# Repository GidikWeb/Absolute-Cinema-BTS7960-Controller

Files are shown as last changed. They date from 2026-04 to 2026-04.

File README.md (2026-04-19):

# D-LEEK Massage Controller / BTS7960 Professional Driver



[]()



**Профессиональный контроллер для массажного аппарата D-LEEK**  
*Победитель регионального этапа Всероссийского конкурса "Юные техники и инновационные лидеры" (2025)*

---

## 📌 О проекте

**D-LEEK** — это открытая, недорогая и функциональная альтернатива дорогостоящим реабилитационным аппаратам (таким как R-Sleek или LPG). Устройство предназначено для медицинской реабилитации после травм, неврологических заболеваний, переломов, а также для восстановительной терапии в домашних условиях.

### 🎯 Ключевые особенности

- **Низкая стоимость** — менее 15 000 рублей (в 100+ раз дешевле аналогов)
- **Профессиональный функционал**:
  - Плавный разгон и торможение (Ramping)
  - Защита по току (Overcurrent protection)
  - Таймер безопасности непрерывной работы
  - 9 предустановленных программ массажа
  - Редактор пользовательских программ (до 5 программ, 10 шагов каждая)
- **Интуитивный интерфейс** — LCD 16×2 с кастомными иконками
- **Управление** — 3 кнопки (Up/OK/Down) + Serial команды
- **Автономность** — все настройки сохраняются в EEPROM

---

## 🧠 Для кого этот проект

- **Пациентам** для самостоятельной реабилитации (под контролем врача)
- **Начинающим реабилитологам и массажистам** для выездной работы
- **Малым медицинским центрам и ФАПам** с ограниченным бюджетом
- **Makers и инженерам**, желающим собрать профессиональный массажёр своими руками

---

## ⚙️ Аппаратная платформа

| Компонент | Модель / Спецификация |
|---|---|
| Микроконтроллер | Arduino Uno (или совместимый) |
| Драйвер двигателя | BTS7960 (43A пик, 27V max) |
| Двигатель | Коллекторный 12V (3-5A рабочий ток) |
| Дисплей | LCD 16×2 с I²C (адрес 0x27) |
| Кнопки | 3 тактовых (BTN_UP, BTN_OK, BTN_DOWN) |
| Питание | Блок питания 12В 5А |
| Корпус и ручка | 3D-печать (PLA) / распределительная коробка |

### Схема подключения (пины Arduino)

| Пин | Назначение |
|-----|---|
| A0  | R_IS (ток) |
| A1  | L_IS (ток) |
| 2 | R_EN |
| 3 | R_PWM |
| 4 | L_EN |
| 5 | L_PWM |
| 8 | BTN_UP |
| 9 | BTN_OK |
| 10  | BTN_DOWN |
| A4  | SDA (I²C дисплей) |
| A5  | SCL (I²C дисплей) |

> Полная схема доступна в [схема/](schematic/)

---

## 🖥️ Программное обеспечение

- **Среда разработки**: VS Code + PlatformIO (или Arduino IDE)
- **Язык**: C++ (Arduino framework)
- **Библиотеки**:
  - `LiquidCrystal_I2C` — управление дисплеем
  - `EEPROM` — хранение настроек
  - `avr/pgmspace.h` — хранение констант в PROGMEM

### 🔁 Конечный автомат состояний

Поддерживаются следующие режимы:
- MAIN_MENU
- SPEED_SETTING
- DIRECTION_SETTING
- TIMER_SETTING
- SAFETY_SETTING
- TIMER_RUNNING
- PROGRAM_MENU / PROGRAM_RUNNING
- AUTO_TEST
- EDITOR_INPUT / EDITOR_NAME / EDITOR_SELECT / EDITOR_EDIT_STEPS

---

## 🎮 Управление

### Через кнопки
- **UP** — увеличение значения / навигация вверх
- **DOWN** — уменьшение значения / навигация вниз / остановка
- **OK** — подтверждение / вход в меню / пауза/возобновление

### Через Serial (115200 бод)

| Команда | Описание |
|---|---|
| `ON` / `OFF` | Включить / выключить мотор |
| `SPEED 150` | Установить скорость (0-255) |
| `DIR F` / `DIR R` | Направление: Forward / Reverse |
| `TIMER 10` | Установить таймер (минут) |
| `START_TIMER` / `STOP_TIMER` | Запуск / остановка таймера |
| `SAFETY 30` | Тайм-аут безопасности (мин) |
| `LIST` | Список всех программ |
| `RUN 2` | Запустить программу по индексу |
| `STOP` / `PAUSE` / `RESUME` | Управление программой |
| `PROG_INFO 0` | Показать шаги программы |
| `EDITOR_NEW` | Создать новую программу |
| `EDITOR_ADD_STEP 150 1 30` | Добавить шаг (скорость, направление, секунды) |
| `EDITOR_SET_NAME MyProg` | Задать имя программы |
| `EDITOR_SAVE` | Сохранить программу в EEPROM |
| `AUTO_TEST` | Запустить автоматическое тестирование |
| `HELP` | Показать все команды |

---

## 📦 Предустановленные программы массажа

| №  | Название | Особенность |
|----|---|---|
| 0  | Hard | Интенсивный, длительные шаги |
| 1  | Relax | Мягкий, расслабляющий |
| 2  | Body | Общеукрепляющий |
| 3  | Arms | Для рук и плечевого пояса |
| 4  | Legs | Для ног |
| 5  | Kneading | Разминание с переменной скоростью |
| 6  | Vibration | Быстрое чередование направлений |
| 7  | Tapping | Имитация постукивания (вкл/выкл) |
| 8  | Lymphatic | Длительный лимфодренаж (60 мин) |

> Пользовательские программы сохраняются в EEPROM (до 5 штук, до 10 шагов).

---

## 🔧 Сборка и настройка

### 1. Установка зависимостей

**Arduino IDE**:
- Установите библиотеку `LiquidCrystal_I2C` через менеджер библиотек

**PlatformIO**:
```ini
[env:uno]
platform = atmelavr
board = uno
framework = arduino
lib_deps = 
    liquidcrystal-i2c

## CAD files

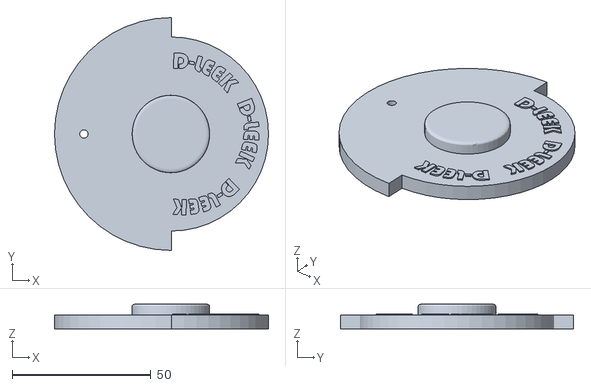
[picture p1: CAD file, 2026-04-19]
3d_models/Upper.stl
77.2 x 84.0 x 9.00

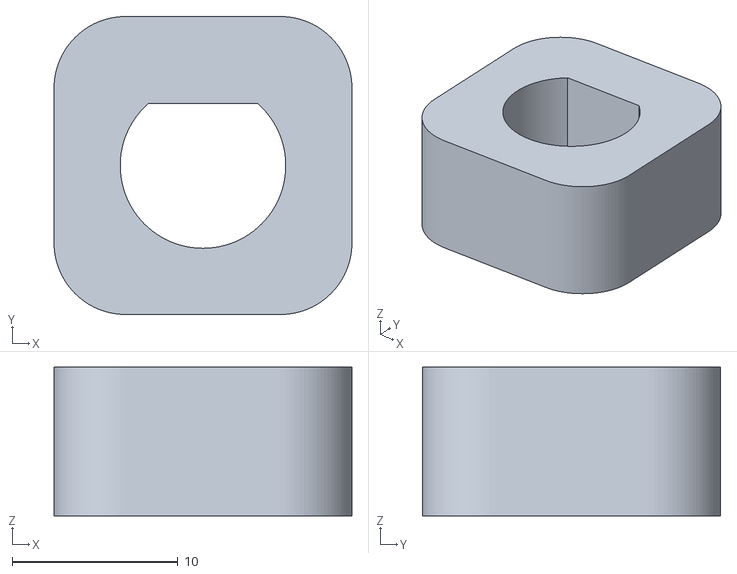
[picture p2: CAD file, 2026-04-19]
3d_models/Locker.stl
18.0 x 18.0 x 9.00

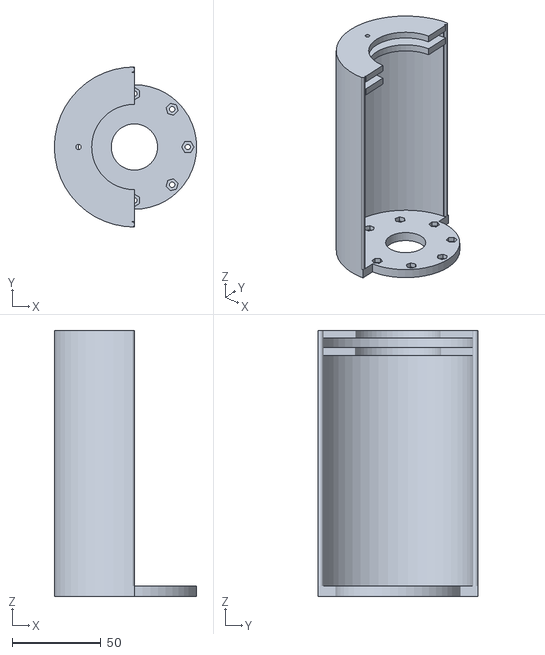
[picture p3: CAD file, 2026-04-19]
3d_models/Handle.stl
80.0 x 90.0 x 149.5

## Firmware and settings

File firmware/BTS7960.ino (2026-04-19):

#include <Wire.h>
#include <LiquidCrystal_I2C.h>
#include <EEPROM.h>
#include <avr/pgmspace.h>

// ========== BTS7960 PINS ==========
int R_IS = A0;
int L_IS = A1;
int R_EN = 2;
int R_PWM = 3;
int L_EN = 4;
int L_PWM = 5;

// ========== BUTTON PINS ==========
#define BTN_UP    8
#define BTN_OK    9
#define BTN_DOWN  10

// ========== LCD I2C ==========
LiquidCrystal_I2C lcd(0x27, 16, 2);

// ========== CUSTOM CHARACTERS (PROGMEM) ==========
const byte char_arrowLeft[8] PROGMEM      = {0b00000,0b00100,0b01000,0b11111,0b01000,0b00100,0b00000,0b00000};
const byte char_timerIcon[8] PROGMEM      = {0b00000,0b01110,0b10101,0b10111,0b10001,0b01110,0b00000,0b00000};
const byte char_pauseIcon[8] PROGMEM      = {0b00000,0b11011,0b11011,0b11011,0b11011,0b11011,0b11011,0b00000};
const byte char_playIcon[8] PROGMEM       = {0b00000,0b01100,0b01110,0b01111,0b01111,0b01110,0b01100,0b00000};
const byte char_speedIcon7[8] PROGMEM     = {0b00000,0b01110,0b10001,0b10101,0b10011,0b11111,0b00000,0b00000};
const byte char_powerOn[8] PROGMEM        = {0b11111,0b11111,0b11011,0b11011,0b11011,0b01110,0b10001,0b11111};
const byte char_powerOff[8] PROGMEM       = {0b00000,0b00000,0b00100,0b00100,0b10101,0b10001,0b01110,0b00000};
const byte char_menuIcon[8] PROGMEM       = {0b00000,0b00000,0b11111,0b00000,0b11111,0b00000,0b11111,0b00000};
const byte char_arrowRight[8] PROGMEM     = {0b00000,0b00100,0b00010,0b11111,0b00010,0b00100,0b00000,0b00000};
const byte char_speedIcon6[8] PROGMEM     = {0b00000,0b01110,0b10001,0b10111,0b10001,0b11111,0b00000,0b00000};
const byte char_speedIcon5[8] PROGMEM     = {0b00000,0b01110,0b10011,0b10101,0b10001,0b11111,0b00000,0b00000};
const byte char_speedIcon4[8] PROGMEM     = {0b00000,0b01110,0b10101,0b10101,0b10001,0b11111,0b00000,0b00000};
const byte char_speedIcon3[8] PROGMEM     = {0b00000,0b01110,0b11001,0b10101,0b10001,0b11111,0b00000,0b00000};
const byte char_speedIcon2[8] PROGMEM     = {0b00000,0b01110,0b10001,0b11101,0b10001,0b11111,0b00000,0b00000};
const byte char_speedIcon1[8] PROGMEM     = {0b00000,0b01110,0b10001,0b10101,0b11001,0b11111,0b00000,0b00000};
const byte char_newIcon[8] PROGMEM        = {0b00000,0b00000,0b00100,0b00100,0b11111,0b00100,0b00100,0b00000};
const byte char_deleteIcon[8] PROGMEM     = {0b00000,0b00000,0b00000,0b00000,0b11111,0b00000,0b00000,0b00000};
const byte char_powerMenu[8] PROGMEM      = {0b00010,0b00110,0b01100,0b11111,0b00011,0b00110,0b00100,0b00000};
const byte char_directionMenu[8] PROGMEM  = {0b00100,0b01111,0b00101,0b00001,0b10001,0b10001,0b11111,0b00000};
const byte char_speedMenu[8] PROGMEM      = {0b00000,0b01110,0b10001,0b10101,0b10011,0b11111,0b00000,0b00000};
const byte char_timersMenu[8] PROGMEM     = {0b00000,0b01110,0b10101,0b10111,0b10001,0b01110,0b00000,0b00000};
const byte char_safetyMenu[8] PROGMEM     = {0b01110,0b10001,0b10001,0b11111,0b11111,0b11011,0b11111,0b00000};
const byte char_massageMenu[8] PROGMEM    = {0b00000,0b00000,0b01010,0b11011,0b00000,0b11011,0b01010,0b00000};
const byte char_editorMenu[8] PROGMEM     = {0b00001,0b00000,0b01010,0b11011,0b00000,0b11011,0b01010,0b00000};
const byte char_autotestMenu[8] PROGMEM   = {0b00000,0b00000,0b00100,0b01110,0b11011,0b01110,0b00100,0b00000};
// Песочные часы (степень заполнения)
const byte timeLeft1[8] PROGMEM           = {0b00000,0b11111,0b10001,0b01010,0b00100,0b01010,0b10001,0b11111};
const byte timeLeft2[8] PROGMEM           = {0b00000,0b11111,0b10001,0b01010,0b00100,0b01010,0b11111,0b11111};
const byte timeLeft3[8] PROGMEM           = {0b00000,0b11111,0b10001,0b01010,0b00100,0b01110,0b11111,0b11111};
const byte timeLeft4[8] PROGMEM           = {0b00000,0b11111,0b10001,0b01110,0b00100,0b01110,0b11111,0b11111};
const byte timeLeft5[8] PROGMEM           = {0b00000,0b11111,0b11111,0b01110,0b00100,0b01110,0b11111,0b11111};

void loadCharFromProgmem(uint8_t slot, const byte* data) {
  byte buffer[8];
  for (int i = 0; i < 8; i++) buffer[i] = pgm_read_byte(&data[i]);
  lcd.createChar(slot, buffer);
}

// ========== EEPROM ADDRESSES ==========
const int EEPROM_SIGNATURE = 0xAA;
const int ADDR_SIGNATURE = 0;
const int ADDR_SPEED     = 1;
const int ADDR_DIRECTION = 2;
const int ADDR_TIMER_MIN = 3;
const int ADDR_SAFETY_TIMEOUT = 4;

#define USER_PROG_START  100
#define USER_PROG_MAX    5
#define USER_PROG_STEPS_MAX 10
#define USER_NAME_LEN    12

// ========== SAFETY SETTINGS ==========
int MAX_CONTINUOUS_MINUTES = 30;
const int CURRENT_THRESHOLD = 600;
unsigned long motorStartTime = 0;
bool safetyTimerActive = false;

// ========== SMOOTH RAMPING ==========
const unsigned long RAMP_TIME_MS = 400;
int currentSpeed = 0;
int targetSpeed = 0;
bool targetEnabled = false;
unsigned long rampStartTime = 0;
bool ramping = false;

// ========== GLOBAL VARIABLES ==========
enum MenuState {
  MAIN_MENU,
  SPEED_SETTING,
  DIRECTION_SETTING,
  TIMER_SETTING,
  SAFETY_SETTING,
  TIMER_RUNNING,
  PROGRAM_MENU,
  PROGRAM_RUNNING,
  AUTO_TEST,
  EDITOR_INPUT,
  EDITOR_NAME,
  EDITOR_SELECT,
  EDITOR_EDIT_STEPS
};

MenuState currentState = MAIN_MENU;
int menuIndex = 0;
bool motorEnabled = false;
int motorSpeed = 150;
bool motorDirection = true;
int timerMinutes = 5;
int safetyMinutes = 30;

bool backgroundTimerActive = false;
unsigned long backgroundTimerEndTime = 0;
bool timerPaused = false;
unsigned long pauseAccumulated = 0;

int currentProgram = -1;
int currentStep = 0;
unsigned long stepStartTime = 0;
unsigned long stepPauseAccum = 0;
bool programPaused = false;

// ========== FACTORY PROGRAMS (PROGMEM) ==========
struct ProgramStep {
  uint8_t speed;
  bool direction;
  uint16_t durationSec;
};

#define readStepSpeed(ptr)   pgm_read_byte(&(ptr)->speed)
#define readStepDir(ptr)     pgm_read_byte(&(ptr)->direction)
#define readStepDur(ptr)     pgm_read_word(&(ptr)->durationSec)

const ProgramStep programHard[] PROGMEM = {
  {200, true, 600}, {180, false, 300}, {220, true, 450}, {150, false, 600}, {0, false, 0}
};
const ProgramStep programRelax[] PROGMEM = {
  {120, true, 600}, {100, false, 600}, {80, true, 300}, {0, false, 0}
};
const ProgramStep programBody[] PROGMEM = {
  {180, true, 600}, {200, false, 600}, {160, true, 600}, {0, false, 0}
};
const ProgramStep programArms[] PROGMEM = {
  {150, true, 300}, {130, false, 300}, {170, true, 300}, {140, false, 300}, {0, false, 0}
};
const ProgramStep programLegs[] PROGMEM = {
  {220, true, 600}, {200, false, 600}, {180, true, 300}, {0, false, 0}
};
const ProgramStep programKneading[] PROGMEM = {
  {180, true, 600}, {160, false, 600}, {200, true, 600}, {140, false, 300}, {170, true, 300}, {0, false, 0}
};
const ProgramStep programVibration[] PROGMEM = {
  {120, true, 2}, {120, false, 2}, {120, true, 2}, {120, false, 2},
  {130, true, 2}, {130, false, 2}, {130, true, 2}, {130, false, 2},
  {140, true, 2}, {140, false, 2}, {140, true, 2}, {140, false, 2},
  {150, true, 2}, {150, false, 2}, {150, true, 2}, {150, false, 2},
  {160, true, 2}, {160, false, 2}, {160, true, 2}, {160, false, 2},
  {170, true, 2}, {170, false, 2}, {170, true, 2}, {170, false, 2},
  {180, true, 2}, {180, false, 2}, {180, true, 2}, {180, false, 2},
  {0, false, 0}
};
const ProgramStep programTapping[] PROGMEM = {
  {220, true, 2}, {0, true, 1}, {220, true, 2}, {0, true, 1},
  {200, true, 2}, {0, true, 1}, {200, true, 2}, {0, true, 1},
  {180, true, 2}, {0, true, 1}, {180, true, 2}, {0, true, 1},
  {160, true, 2}, {0, true, 1}, {160, true, 2}, {0, true, 1},
  {140, true, 2}, {0, true, 1}, {140, true, 2}, {0, true, 1},
  {120, true, 2}, {0, true, 1}, {120, true, 2}, {0, true, 1},
  {0, false, 0}
};
const ProgramStep programLymphatic[] PROGMEM = {
  {100, true, 3600}, {0, false, 0}
};

PGM_P const factoryPrograms[] PROGMEM = {
  (PGM_P)programHard, (PGM_P)programRelax, (PGM_P)programBody,
  (PGM_P)programArms, (PGM_P)programLegs, (PGM_P)programKneading,
  (PGM_P)programVibration, (PGM_P)programTapping, (PGM_P)programLymphatic
};

const char factoryProgramNames[9][8] PROGMEM = {
  "Hard", "Relax", "Body", "Arms", "Legs",
  "Kneading", "Vibration", "Tapping", "Lymphatic"
};
const int factoryProgramCount = 9;
int totalProgramCount = factoryProgramCount;

// ========== USER PROGRAMS ==========
struct UserProgram {
  char name[USER_NAME_LEN+1];
  uint8_t stepCount;
  struct Step {
    uint8_t speed;
    bool direction;
    uint16_t durationSec;
  } steps[USER_PROG_STEPS_MAX];
};

UserProgram userPrograms[USER_PROG_MAX];
int userProgramCount = 0;

UserProgram editingProg;
int editingStepIndex = 0;
int editingParam = 0;
bool isEditing = false;
int editingProgIndex = -1;

unsigned long lastBlink = 0;
bool blinkState = false;
unsigned long lastButtonPress = 0;
const int DEBOUNCE_DELAY = 150;

// ========== PROTOTYPES ==========
void loadSettings();
void saveSettings();
void updateMotorRamp();
void setMotorTarget(bool enable, int speed, bool direction);
void applyPWM(int speed);
void updateMotor();
void checkCurrentProtection();
void safetyMotorOff();
void startTimer();
void stopBackgroundTimer();
void handleBackgroundTimer();
void startProgram(int progIndex);
void stopProgram();
void applyStepFromProgmem(PGM_P stepPtr);
void applyUserStep(const UserProgram::Step& step);
void handleProgramStep();
void runAutoTest();
void updateDisplay();
void showMainMenu();
void showSpeedSetting();
void showDirectionSetting();
void showTimerSetting();
void showSafetySetting();
void showTimerRunning();
void showProgramMenu();
void showProgramRunning();
void showAutoTest();
void showEditorInput();
void showEditorName();
void showEditorSelect();
void showEditorEditSteps();
void showSplashScreen();
void showCenteredMessage(const char* msg, int ms);
bool buttonPressed();
void checkButtons();
void handleButtonUp();
void handleButtonDown();
void handleButtonOk();
void loadIconForMenuItem(int idx);
void setSpeedIcon(int speed);
void setHourglassIcon(unsigned long remaining, unsigned long total);
void loadUserPrograms();
void saveUserProgram(int idx, const UserProgram& prog);
bool deleteUserProgram(int idx);
int findFreeUserSlot();
void startNewProgram();
void startEditProgram(int progIdx);
void commitEditingProgram();
void deleteUserProgramFromList(int progIdx);
void processSerialCommands();

// ========== SETUP ==========
void setup() {
  Serial.begin(115200);
  Serial.println(F("=== BTS7960 Pro Massage Controller ==="));

  pinMode(R_IS, INPUT);
  pinMode(L_IS, INPUT);
  pinMode(R_EN, OUTPUT);
  pinMode(L_EN, OUTPUT);
  pinMode(R_PWM, OUTPUT);
  pinMode(L_PWM, OUTPUT);
  digitalWrite(R_EN, HIGH);
  digitalWrite(L_EN, HIGH);
  analogWrite(R_PWM, 0);
  analogWrite(L_PWM, 0);

  pinMode(BTN_UP, INPUT_PULLUP);
  pinMode(BTN_OK, INPUT_PULLUP);
  pinMode(BTN_DOWN, INPUT_PULLUP);

  Wire.begin();
  lcd.init();
  lcd.backlight();
  lcd.clear();

  // Загружаем часто используемые символы из PROGMEM
  loadCharFromProgmem(0, char_arrowRight);
  loadCharFromProgmem(1, char_arrowLeft);
  loadCharFromProgmem(2, char_playIcon);
  loadCharFromProgmem(3, char_pauseIcon);
  loadCharFromProgmem(4, timeLeft1); // начальные песочные часы
  loadCharFromProgmem(6, char_powerOn);
  loadCharFromProgmem(7, char_menuIcon);
  // Слот 5 остаётся для динамической иконки скорости

  loadSettings();
  loadUserPrograms();
  totalProgramCount = factoryProgramCount + userProgramCount;

  showSplashScreen();
  updateDisplay();

  currentSpeed = 0;
  targetSpeed = 0;
  targetEnabled = false;
  updateMotorRamp();
}

// ========== MAIN LOOP ==========
void loop() {
  processSerialCommands();
  checkButtons();
  updateMotorRamp();
  checkCurrentProtection();

  if (motorEnabled && !safetyTimerActive) {
    safetyTimerActive = true;
    motorStartTime = millis();
  }
  if (!motorEnabled && safetyTimerActive) safetyTimerActive = false;
  if (safetyTimerActive && (millis() - motorStartTime > (MAX_CONTINUOUS_MINUTES * 60000UL))) {
    safetyMotorOff();
    showCenteredMessage("Safety Timeout!", 2000);
  }

  if (backgroundTimerActive) handleBackgroundTimer();
  if (currentState == PROGRAM_RUNNING && !programPaused) handleProgramStep();

  if (currentState == SPEED_SETTING || currentState == DIRECTION_SETTING ||
      currentState == TIMER_SETTING || currentState == SAFETY_SETTING ||
      currentState == TIMER_RUNNING || currentState == PROGRAM_MENU || 
      currentState == PROGRAM_RUNNING || currentState == EDITOR_INPUT ||
      currentState == EDITOR_NAME || currentState == EDITOR_SELECT ||
      currentState == EDITOR_EDIT_STEPS) {
    if (millis() - lastBlink > 500) {
      blinkState = !blinkState;
      lastBlink = millis();
      updateDisplay();
    }
  }
  delay(50);
}

// ========== SMOOTH RAMPING ==========
void setMotorTarget(bool enable, int speed, bool direction) {
  targetEnabled = enable;
  targetSpeed = speed;
  motorDirection = direction;
  if (!enable) targetSpeed = 0;
  rampStartTime = millis();
  ramping = true;
}

void updateMotorRamp() {
  if (!ramping) {
    if (currentSpeed != targetSpeed) {
      rampStartTime = millis();
      ramping = true;
    } else {
      applyPWM(currentSpeed);
      return;
    }
  }

  unsigned long elapsed = millis() - rampStartTime;
  float t = (elapsed >= RAMP_TIME_MS) ? 1.0 : (float)elapsed / RAMP_TIME_MS;
  int newSpeed = currentSpeed + (int)((targetSpeed - currentSpeed) * t);
  if (newSpeed != currentSpeed) {
    currentSpeed = newSpeed;
    applyPWM(currentSpeed);
  }

  if (elapsed >= RAMP_TIME_MS || currentSpeed == targetSpeed) {
    currentSpeed = targetSpeed;
    applyPWM(currentSpeed);
    ramping = false;
  }
}

void applyPWM(int speed) {
  if (!targetEnabled && speed == 0) {
    analogWrite(R_PWM, 0);
    analogWrite(L_PWM, 0);
    return;
  }
  if (motorDirection) {
    analogWrite(R_PWM, speed);
    analogWrite(L_PWM, 0);
  } else {
    analogWrite(R_PWM, 0);
    analogWrite(L_PWM, speed);
  }
}

void updateMotor() {
  if (motorEnabled) {
    setMotorTarget(true, motorSpeed, motorDirection);
  } else {
    setMotorTarget(false, motorSpeed, motorDirection);
  }
}

// ========== CURRENT PROTECTION ==========
void checkCurrentProtection() {
  static unsigned long lastCheck = 0;
  if (millis() - lastCheck < 100) return;
  lastCheck = millis();

  if (!motorEnabled) return;
  int currentR = analogRead(R_IS);
  int currentL = analogRead(L_IS);
  if (currentR > CURRENT_THRESHOLD || currentL > CURRENT_THRESHOLD) {
    safetyMotorOff();
    showCenteredMessage("Overcurrent!", 2000);
  }
}

void safetyMotorOff() {
  motorEnabled = false;
  targetEnabled = false;
  targetSpeed = 0;
  ramping = true;
  rampStartTime = millis();
  backgroundTimerActive = false;
  stopProgram();
  currentState = MAIN_MENU;
  updateDisplay();
}

// ========== TIMER FUNCTIONS ==========
void startTimer() {
  backgroundTimerActive = true;
  timerPaused = false;
  backgroundTimerEndTime = millis() + (timerMinutes * 60000UL);
  motorEnabled = true;
  updateMotor();
  currentState = TIMER_RUNNING;
  updateDisplay();
  showCenteredMessage("Timer Started", 600);
}

void stopBackgroundTimer() {
  backgroundTimerActive = false;
  timerPaused = false;
  motorEnabled = false;
  updateMotor();
}

void handleBackgroundTimer() {
  if (!backgroundTimerActive || timerPaused) return;
  if (millis() >= backgroundTimerEndTime) {
    backgroundTimerActive = false;
    motorEnabled = false;
    updateMotor();
    if (currentState == TIMER_RUNNING) currentState = MAIN_MENU;
    showCenteredMessage("Time's Up!", 2000);
    updateDisplay();
  }
}

// ========== PROGRAM EXECUTION ==========
void applyStepFromProgmem(PGM_P stepPtr) {
  uint8_t sp = pgm_read_byte(stepPtr);
  if (sp == 0) {
    motorEnabled = false;
  } else {
    motorSpeed = sp;
    motorDirection = pgm_read_byte(stepPtr + 1);
    motorEnabled = true;
  }
  updateMotor();
}

void applyUserStep(const UserProgram::Step& step) {
  if (step.speed == 0) {
    motorEnabled = false;
  } else {
    motorSpeed = step.speed;
    motorDirection = step.direction;
    motorEnabled = true;
  }
  updateMotor();
}

void startProgram(int progIndex) {
  currentProgram = progIndex;
  currentStep = 0;
  programPaused = false;
  if (progIndex < factoryProgramCount) {
    PGM_P steps = (PGM_P)pgm_read_word(&factoryPrograms[progIndex]);
    applyStepFromProgmem(steps);
  } else {
    int userIdx = progIndex - factoryProgramCount;
    if (userIdx < userProgramCount) {
      applyUserStep(userPrograms[userIdx].steps[0]);
    } else {
      currentState = MAIN_MENU;
      return;
    }
  }
  stepStartTime = millis();
  currentState = PROGRAM_RUNNING;
  updateDisplay();
}

void stopProgram() {
  programPaused = false;
  motorEnabled = false;
  updateMotor();
  currentProgram = -1;
}

void handleProgramStep() {
  if (currentProgram < factoryProgramCount) {
    PGM_P steps = (PGM_P)pgm_read_word(&factoryPrograms[currentProgram]);
    PGM_P stepPtr = steps + currentStep * sizeof(ProgramStep);
    uint8_t sp = pgm_read_byte(stepPtr);
    if (sp == 0) {
      motorEnabled = false;
      updateMotor();
      currentState = MAIN_MENU;
      showCenteredMessage("Program Done!", 1500);
      updateDisplay();
      return;
    }
    unsigned long elapsed = millis() - stepStartTime;
    uint16_t dur = pgm_read_word(stepPtr + 2);
    if (elapsed >= dur * 1000UL) {
      currentStep++;
      stepPtr += sizeof(ProgramStep);
      sp = pgm_read_byte(stepPtr);
      if (sp == 0) {
        motorEnabled = false;
        updateMotor();
        currentState = MAIN_MENU;
        showCenteredMessage("Program Done!", 1500);
        updateDisplay();
        return;
      }
      applyStepFromProgmem(stepPtr);
      stepStartTime = millis();
      updateDisplay();
    }
  } else {
    int userIdx = currentProgram - factoryProgramCount;
    if (userIdx < userProgramCount) {
      UserProgram& prog = userPrograms[userIdx];
      if (currentStep >= prog.stepCount || prog.steps[currentStep].speed == 0) {
        motorEnabled = false;
        updateMotor();
        currentState = MAIN_MENU;
        showCenteredMessage("Program Done!", 1500);
        updateDisplay();
        return;
      }
      unsigned long elapsed = millis() - stepStartTime;
      unsigned long stepDuration = prog.steps[currentStep].durationSec * 1000UL;
      if (elapsed >= stepDuration) {
        currentStep++;
        if (currentStep >= prog.stepCount || prog.steps[currentStep].speed == 0) {
          motorEnabled = false;
          updateMotor();
          currentState = MAIN_MENU;
          showCenteredMessage("Program Done!", 1500);
          updateDisplay();
          return;
        }
        applyUserStep(prog.steps[currentStep]);
        stepStartTime = millis();
        updateDisplay();
      }
    }
  }
}

// ========== AUTO TEST ==========
void runAutoTest() {
  currentState = AUTO_TEST; updateDisplay();
  showCenteredMessage("Auto Test", 800);
  for(int i=0; i<=200; i+=40){
    lcd.clear(); lcd.setCursor(0,0); lcd.print(F("Test:Forward")); lcd.setCursor(0,1); lcd.print(F("Speed:")); lcd.print(i);
    motorEnabled = true; motorSpeed = i; motorDirection = true; updateMotor();
    delay(500); if(buttonPressed()) break;
  }
  delay(1000);
  for(int i=0; i<=200; i+=40){
    lcd.clear(); lcd.setCursor(0,0); lcd.print(F("Test:Reverse")); lcd.setCursor(0,1); lcd.print(F("Speed:")); lcd.print(i);
    motorEnabled = true; motorSpeed = i; motorDirection = false; updateMotor();
    delay(500); if(buttonPressed()) break;
  }
  motorEnabled = false; updateMotor();
  showCenteredMessage("Test Complete",1000);
  currentState = MAIN_MENU; updateDisplay();
}

// ========== DISPLAY ==========
int getMenuCount() {
  return 9 + 1;
}

const char* getMenuItem(int index) {
  static const char items[10][12] PROGMEM = {
    "Power", "Speed", "Direction", "Timer Set", "Timer Run",
    "Safety", "Programs", "Create Prog", "Edit/Del", "Auto Test"
  };
  static char buffer[12];
  if (index == 9) {
    return backgroundTimerActive ? "Stop Timer" : "Auto Test";
  }
  strcpy_P(buffer, items[index]);
  return buffer;
}

void loadIconForMenuItem(int idx) {
  if (idx == 9) {
    loadCharFromProgmem(7, char_autotestMenu);
    return;
  }
  switch(idx) {
    case 0: loadCharFromProgmem(7, char_powerMenu); break;
    case 1: loadCharFromProgmem(7, char_speedMenu); break;
    case 2: loadCharFromProgmem(7, char_directionMenu); break;
    case 3: loadCharFromProgmem(7, char_timersMenu); break;
    case 4: loadCharFromProgmem(7, char_timersMenu); break;
    case 5: loadCharFromProgmem(7, char_safetyMenu); break;
    case 6: loadCharFromProgmem(7, char_massageMenu); break;
    case 7: loadCharFromProgmem(7, char_editorMenu); break;
    case 8: loadCharFromProgmem(7, char_deleteIcon); break;
    default: loadCharFromProgmem(7, char_autotestMenu); break;
  }
}

void setSpeedIcon(int speed) {
  int level = constrain(speed, 0, 255);
  level = map(level, 0, 255, 1, 7);
  switch(level) {
    case 1: loadCharFromProgmem(5, char_speedIcon1); break;
    case 2: loadCharFromProgmem(5, char_speedIcon2); break;
    case 3: loadCharFromProgmem(5, char_speedIcon3); break;
    case 4: loadCharFromProgmem(5, char_speedIcon4); break;
    case 5: loadCharFromProgmem(5, char_speedIcon5); break;
    case 6: loadCharFromProgmem(5, char_speedIcon6); break;
    case 7: loadCharFromProgmem(5, char_speedIcon7); break;
    default: loadCharFromProgmem(5, char_speedIcon4); break;
  }
}

void setHourglassIcon(unsigned long remaining, unsigned long total) {
  if (total == 0) return;
  int percent = (remaining * 100) / total;
  if (percent > 80) {
    loadCharFromProgmem(4, timeLeft1);
  } else if (percent > 60) {
    loadCharFromProgmem(4, timeLeft2);
  } else if (percent > 40) {
    loadCharFromProgmem(4, timeLeft3);
  } else if (percent > 20) {
    loadCharFromProgmem(4, timeLeft4);
  } else {
    loadCharFromProgmem(4, timeLeft5);
  }
}
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

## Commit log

2026-04-19 Улучшение README
2026-04-19 fill
    fill
    [Handle.stl, Locker.stl, Upper.stl]
2026-04-19 Улучшение README 2

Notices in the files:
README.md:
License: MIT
